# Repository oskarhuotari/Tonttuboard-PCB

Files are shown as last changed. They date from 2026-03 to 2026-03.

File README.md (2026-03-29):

A carrier board for a Teensy 4.0 made for the 2026 Finnish CanSat competition.



---
The board includes:
- Holes for the Teensy 4.0
- ICM-40609-D (IMU)
- BMP388 (Barometer)
- W25Q256JVFIQT (Flash Chip)
- LDR holes
- Thermistor holes
- PMW cable holes
- cool graphics
---
Insturctions:
- Buy a teensy 4.0 and order this PCB from JLCPCB
- Solder them together
- Use Tonttulib (or make your own libs for the sensors)
- Fly your project
- Cry

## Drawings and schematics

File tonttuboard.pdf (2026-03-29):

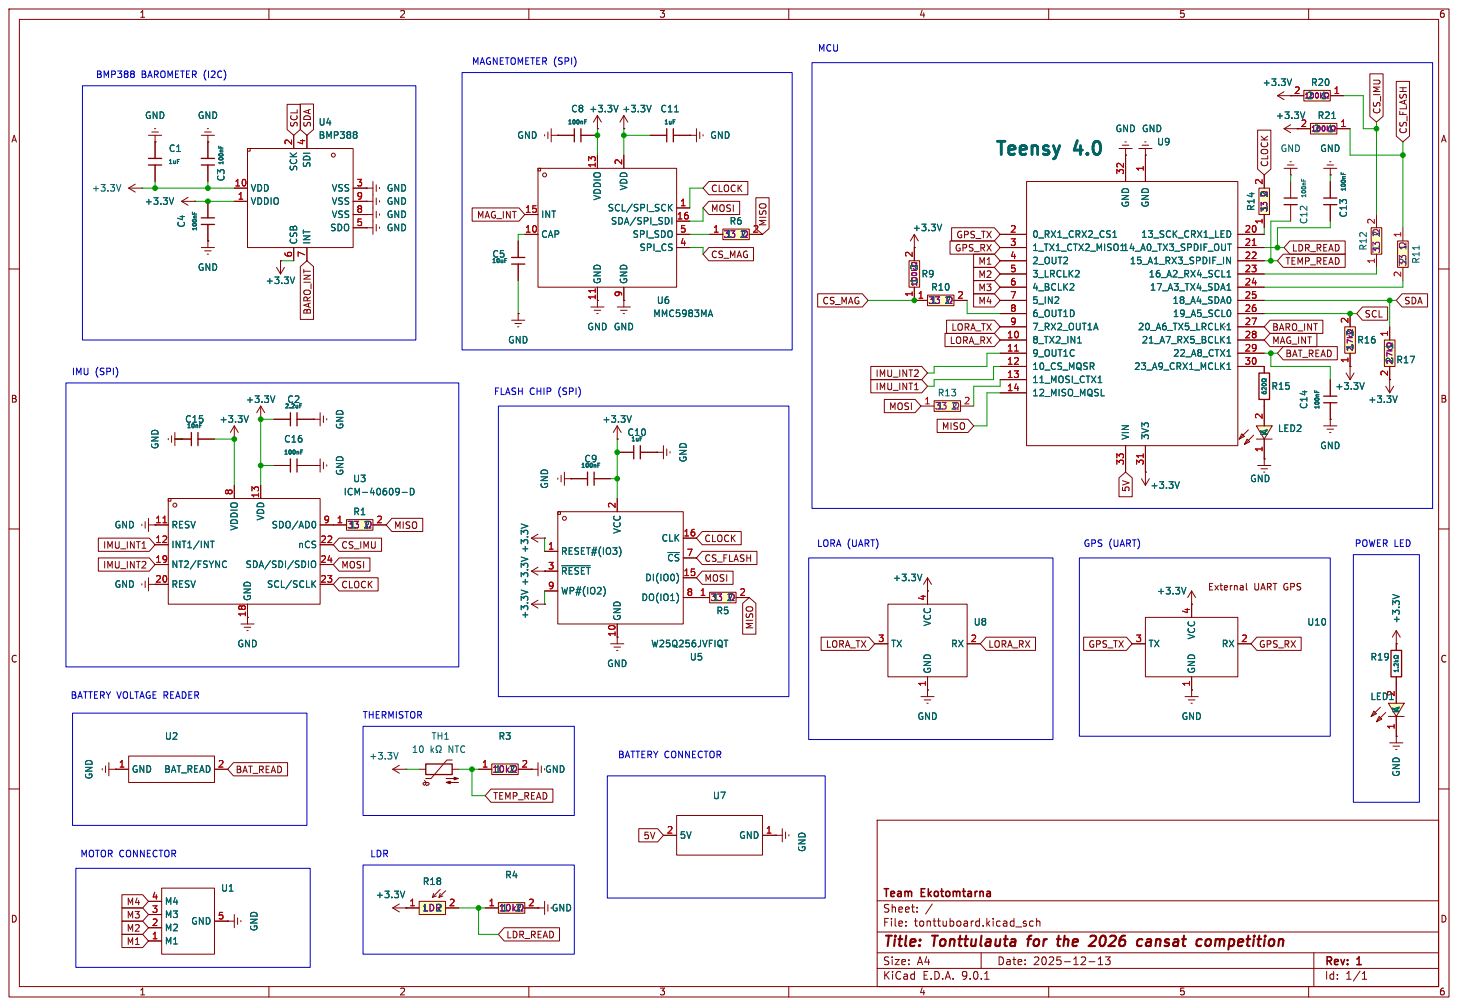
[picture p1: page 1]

7 VSS 3 VSS 9 VSS 8 SDO 5 GND

7 VSS 3 VSS 9 VSS 8 SDO 5 U4BMP388 External UART GPS

2 þÿ2.7k© R17 +3.3V R15 þÿ620© GND C14 100nF +3.3V GND

2 SCL/SPI_SCK 1 SDA/SPI_SDI 16 SPI_SDO 5 SPI_CS 4 CAP 10 GND

IMU (SPI) BATTERY VOLTAGE READER MOTOR CONNECTOR

Id: 1/1 Title: Tonttulauta for the 2026 cansat competition

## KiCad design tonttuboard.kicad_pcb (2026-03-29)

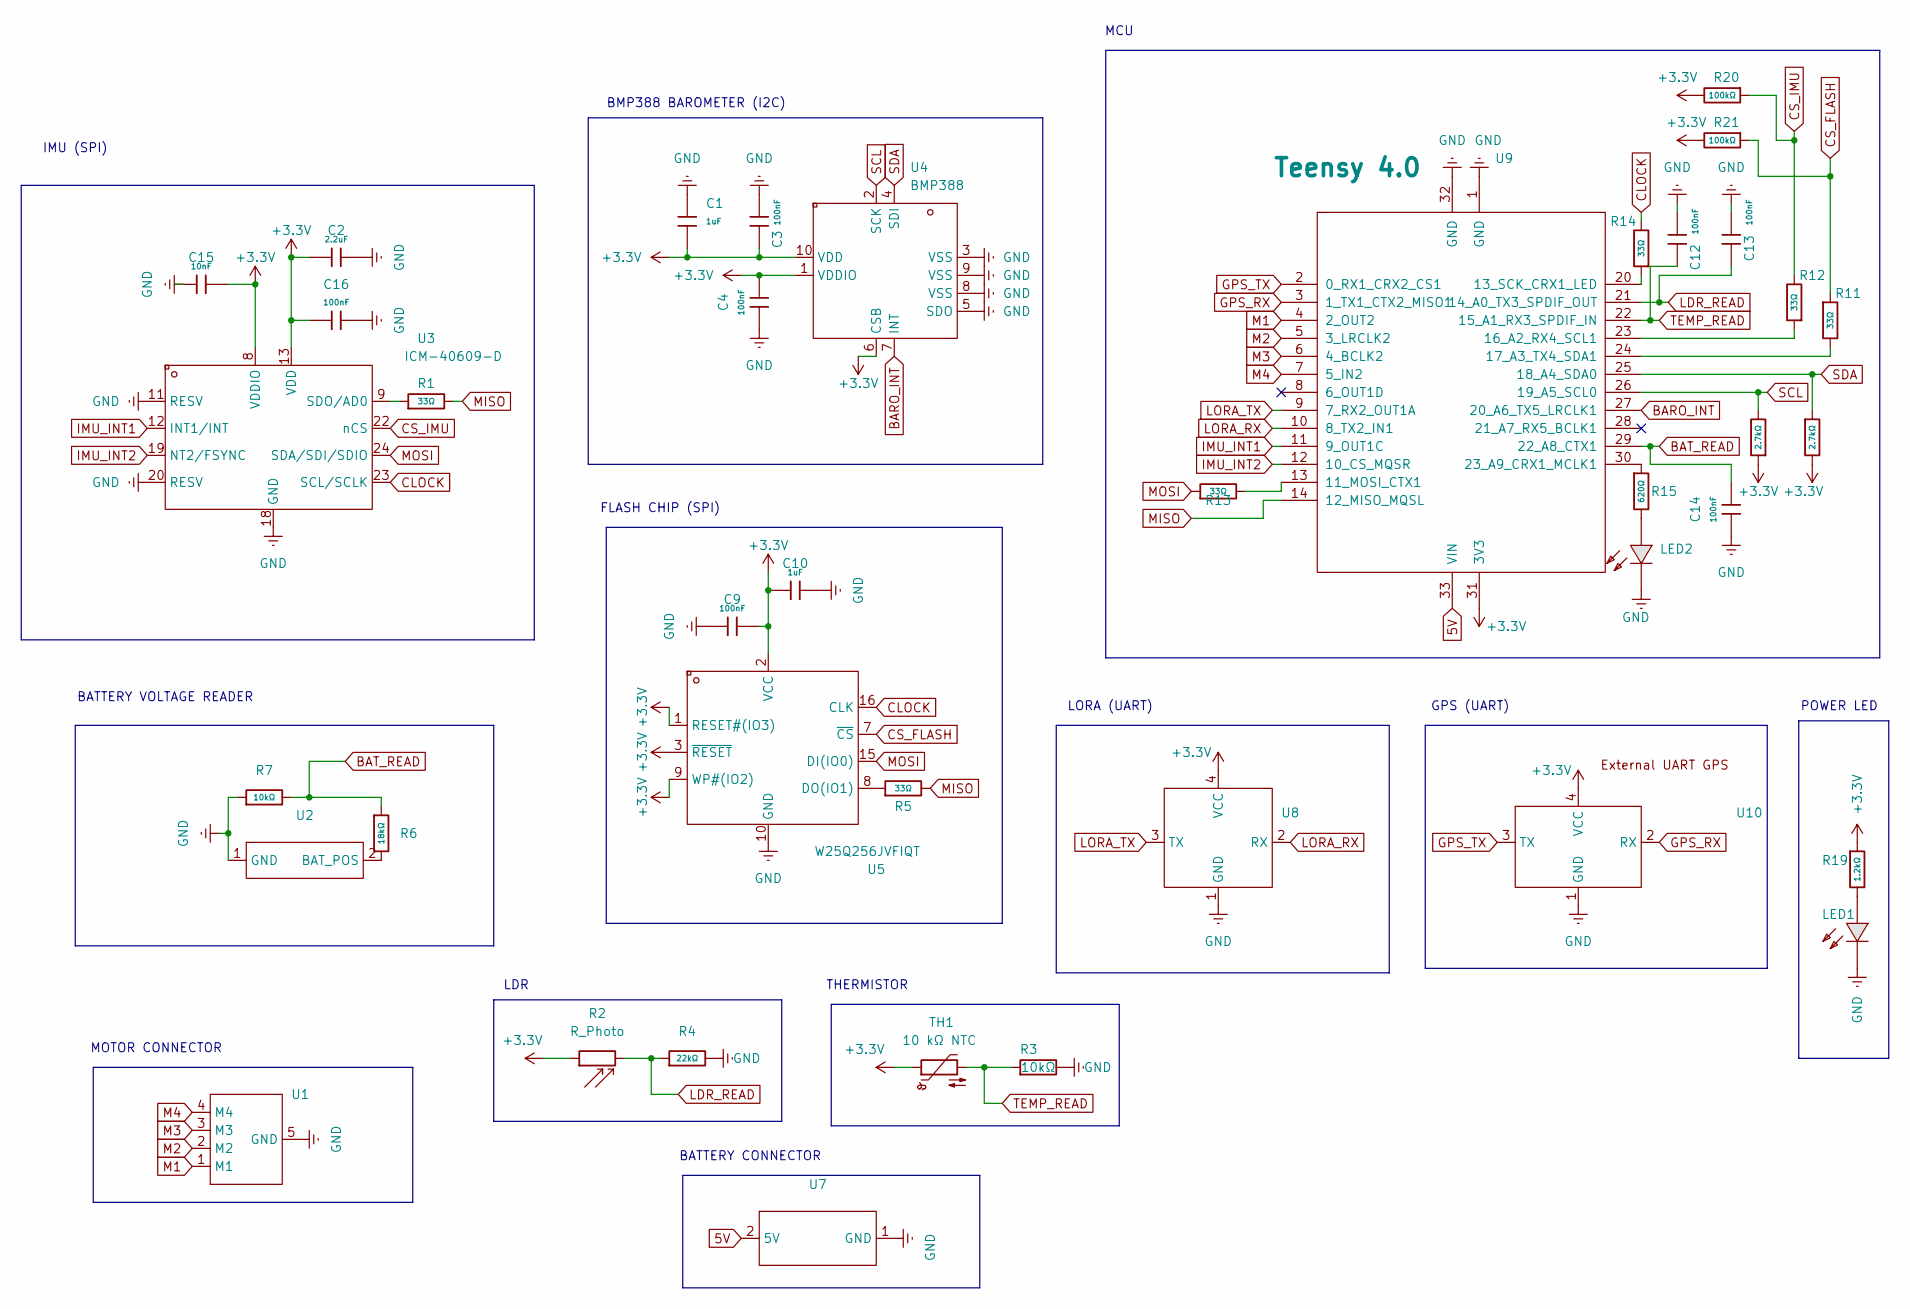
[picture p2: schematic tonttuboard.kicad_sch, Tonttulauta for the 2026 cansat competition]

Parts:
C1, C10: 1uF; C_0603; Voltage Rated 50V; Tolerance ±10%; Part CL10A105KB8NNNC; LCSC C15849
C2: 2.2uF; C_0603; Voltage Rated 16V; Tolerance ±10%; Part CL10A225KO8NNNC; LCSC C23630
C3, C4, C9, C12, C13, C14, C16: 100nF; C_0603; Voltage Rated 50V; Tolerance ±10%; Part CC0603KRX7R9BB104; LCSC C14663
C15: 10nF; C_0603; Voltage Rated 50V; Tolerance ±10%; Part 0603B103K500NT; LCSC C57112
LED1: FC-DA1608HRK-620D; LED0603-RD_RED; LCSC Part C84263
LED2: FC-D1608UGK-520D10; LED0603-RD_1; LCSC Part C84267
R1, R5, R11, R12, R13, R14: 33Ω; R_0603; Tolerance ±1%; LCSC Part C108661
R2: R_Photo; LDR-holes
R3: 0603WAF1002T5E; R_0603; Overload Voltage (Max) 75V; Tolerance ±1%; Part 0603WAF1002T5E; LCSC Part C25804
R4: 22kΩ; R_0603; Overload Voltage (Max) 75V; Tolerance ±1%; Part 0603WAF2202T5E; LCSC C31850
R6: 18kΩ; R_0603; Overload Voltage (Max) 75V; Tolerance ±1%; Part 0603WAF1802T5E; LCSC C25810
R7: 10kΩ; R_0603; Overload Voltage (Max) 75V; Tolerance ±1%; Part 0603WAF1002T5E; LCSC C25804
R15: 620Ω; R_0603; Overload Voltage (Max) 75V; Tolerance ±1%; Part 0603WAF6200T5E; LCSC C23220
R16, R17: 2.7kΩ; R_0603; LCSC Part C13167
R19: 1.2kΩ; R_0603; Overload Voltage (Max) 75V; Tolerance ±1%; Part 0603WAF1201T5E; LCSC C22765
R20, R21: 100kΩ; R_0603; Overload Voltage (Max) 75V; Tolerance ±1%; Part 0603WAF1003T5E; LCSC Part C25803
TH1: 10 kΩ NTC; Thermistor-holes
U1: Motor-connector
U2: Voltage-read
U3: ICM-40609-D; LGA-24_L3.0-W3.0-P0.40-TL; LCSC Part C5360621
U4: BMP388; SENSORM-SMD_BMP388; LCSC Part C779278
U5: W25Q256JVFIQT; SOIC-16_L10.3-W7.5-P1.27-LS10.3-BL; LCSC Part C779876
U7: Battery-connector
U8, U10: UART-connector
U9: Teensy 4.0; Teensy40

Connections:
5V: U7.2 (5V), U9.33 (VIN)
+3.3V: C1.2, C2.1, C3.1, C4.2, C9.2, C10.1, C15.2, C16.1, R2.1, R16.1, R17.2, R19.1, R20.2, R21.2, TH1.1, U3.8 (VDDIO), U3.13 (VDD), U4.1 (VDDIO), U4.6 (CSB), U4.10 (VDD), U5.1 (RESET#(IO3)), U5.2 (VCC), U5.3 (~RESET), U5.9 (WP#(IO2)), U8.4 (VCC), U9.31 (3V3), U10.4 (VCC)
BARO_INT: U4.7 (INT), U9.27 (20_A6_TX5_LRCLK1)
BAT_READ: C14.2, R6.1, R7.2, U9.29 (22_A8_CTX1)
CLOCK: R14.2, U3.23 (SCL/SCLK), U5.16 (CLK)
CS_FLASH: R11.1, R21.1, U5.7 (~CS)
CS_IMU: R12.2, R20.1, U3.22 (nCS)
GND: C1.1, C2.2, C3.2, C4.1, C9.1, C10.2, C12.2, C13.2, C14.1, C15.1, C16.2, LED1.1 (K), LED2.1 (K), R3.2, R4.2, R7.1, U1.5 (GND), U2.1 (GND), U3.11 (RESV), U3.18 (GND), U3.20 (RESV), U4.3 (VSS), U4.5 (SDO), U4.8 (VSS), U4.9 (VSS), U5.10 (GND), U7.1 (GND), U8.1 (GND), U9.1 (GND), U9.32 (GND), U10.1 (GND)
GPS_RX: U9.3 (1_TX1_CTX2_MISO1), U10.2 (RX)
GPS_TX: U9.2 (0_RX1_CRX2_CS1), U10.3 (TX)
IMU_INT1: U3.12 (INT1/INT), U9.11 (9_OUT1C)
IMU_INT2: U3.19 (NT2/FSYNC), U9.12 (10_CS_MQSR)
LDR_READ: C13.1, R2.2, R4.1, U9.21 (14_A0_TX3_SPDIF_OUT)
LORA_RX: U8.2 (RX), U9.10 (8_TX2_IN1)
LORA_TX: U8.3 (TX), U9.9 (7_RX2_OUT1A)
M1: U1.1 (M1), U9.4 (2_OUT2)
M2: U1.2 (M2), U9.5 (3_LRCLK2)
M3: U1.3 (M3), U9.6 (4_BCLK2)
M4: U1.4 (M4), U9.7 (5_IN2)
MISO: R1.2, R5.2, U9.14 (12_MISO_MQSL)
MOSI: R13.1, U3.24 (SDA/SDI/SDIO), U5.15 (DI(IO0))
unnamed: LED1.2 (A), R19.2
unnamed: LED2.2 (A), R15.2
unnamed: R6.2, U2.2 (BAT_POS)
unnamed: R1.1, U3.9 (SDO/AD0)
unnamed: R5.1, U5.8 (DO(IO1))
unnamed: R13.2, U9.13 (11_MOSI_CTX1)
unnamed: R14.1, U9.20 (13_SCK_CRX1_LED)
unnamed: R12.1, U9.23 (16_A2_RX4_SCL1)
unnamed: R11.2, U9.24 (17_A3_TX4_SDA1)
unnamed: R15.1, U9.30 (23_A9_CRX1_MCLK1)
SCL: R16.2, U4.2 (SCK), U9.26 (19_A5_SCL0)
SDA: R17.1, U4.4 (SDI), U9.25 (18_A4_SDA0)
TEMP_READ: C12.1, R3.1, TH1.2, U9.22 (15_A1_RX3_SPDIF_IN)

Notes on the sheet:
BMP388 BAROMETER (I2C)
LORA (UART)
BATTERY CONNECTOR
IMU (SPI)
THERMISTOR
FLASH CHIP (SPI)
MCU
BATTERY VOLTAGE READER
GPS (UART)
LDR
POWER LED
MOTOR CONNECTOR

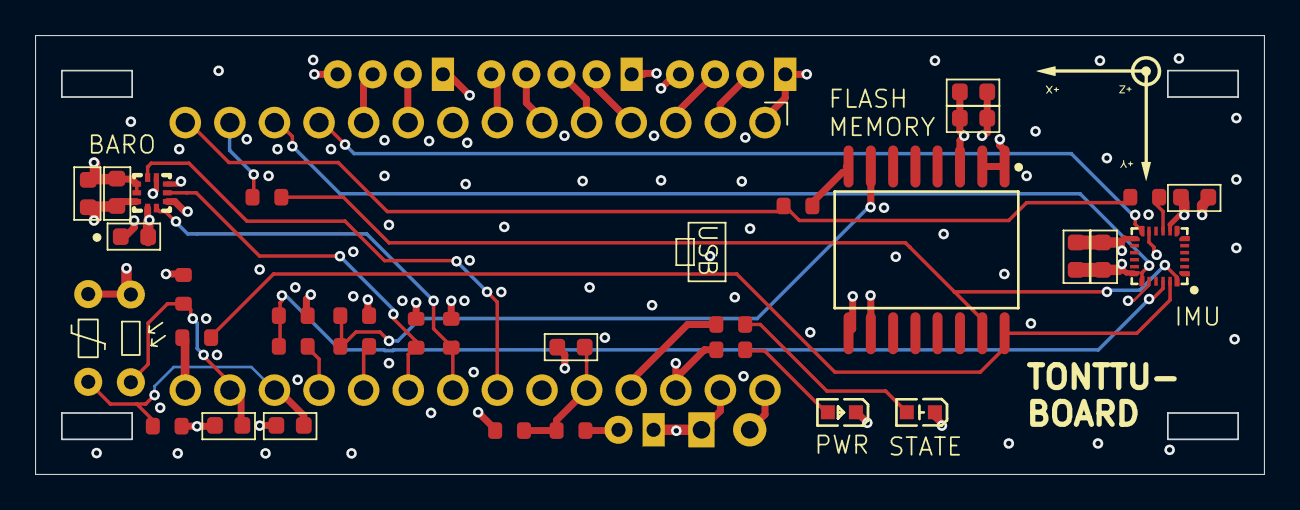
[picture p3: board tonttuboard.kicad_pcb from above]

Board: 4 copper layers, 70.0 x 25.0 mm, 40 parts (0 on the bottom side), 34 nets.

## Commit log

2025-12-18 Tonttuboard inital commit
    [tonttuboard.kicad_pcb, tonttuboard.kicad_sch]
2025-12-18 Made a netclass for power.
    [tonttuboard.kicad_sch]
2025-12-18 Improved component placement
    [tonttuboard.kicad_pcb, tonttuboard.kicad_sch]
2025-12-20 Routed signals
    [tonttuboard.kicad_pcb]
2025-12-21 Added gnd vias and decorated
    [tonttuboard.kicad_pcb, tonttuboard.kicad_sch]
2025-12-21 Improved clearances and silkscreen, added copper fill on l4 and vias
    [tonttuboard.kicad_pcb]
2025-12-21 Add README for Teensy 4.0 carrier board project
    Added project description and component list for the Teensy 4.0 carrier board.
2025-12-23 Replaced LDR with a through hole due to a soldering temperature issue. Also made the thermistor silk screen better and fixed a typo. Added CanSat 2026 Vaasa text to the back silkscreen
    [tonttuboard.kicad_pcb, tonttuboard.kicad_sch]
2025-12-23 Added a few footprints
2026-01-18 Changed the CS Magnetometer 100 kohm pull-up to 4.7 kohm pulldown
    [tonttuboard.kicad_pcb, tonttuboard.kicad_sch]
2026-03-29 Removed magnetometer and changed component placement
    [tonttuboard.kicad_pcb, tonttuboard.kicad_sch]
